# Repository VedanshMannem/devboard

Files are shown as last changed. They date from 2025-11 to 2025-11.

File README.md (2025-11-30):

# Devboard
This project contains all the files of my first devboard. This is great for electronics engineering and hobbyists, with a USBC and RP2040. I included LEDs on this board to make it more flashy, as well as silkscreen art to make it personal. The full BOMs are attached (there's two - one from JLCPCB and one from KiCAD). 

## Setup
All the KiCAD project files are available in the KiCAD folder, and there's photos of the devboard included as well for a rough outline of the end product. Hardest part of this project is honeslty the routing, but as long as you place all the components in the right place, the routing shouldn't be that bad. I went through a few versions of the board to make sure the routing was just right. Try to save the vias for the end as well, its just better practice and I think the board will look less messy without them. 

Here's some photos:






Overall, learned a ton because this was my first full scale PCB project. Thanks for reading!

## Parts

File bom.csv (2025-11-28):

Comment | Designator | Footprint | JLCPCB Part #
10uF | C14,C13 | C_0402_1005Metric | C15525
MCP1700x-330xxTT | U4 | SOT-23 | C39051
33pF | C15,C16 | C_0402_1005Metric | C1562
1K | R5,R7 | R_0402_1005Metric | C11702
LED | D3,D2,D1,D4 | LED_0402_1005Metric_Pad0.77x0.64mm_HandSolder | C71911
Conn_01x03 | J4 | PinHeader_1x03_P2.54mm_Vertical | C92159
5.1K | R2,R1 | R_0402_1005Metric | C25905
12MHz | Y1 | Crystal_SMD_3225-4Pin_3.2x2.5mm | C9002
W25Q16JVSS | U2 | Winbond_USON-8-1EP_3x2mm_P0.5mm_EP0.2x1.6mm | C131025
RP2040 | U1 | QFN-56-1EP_7x7mm_P0.4mm_EP3.2x3.2mm | C2040
1uF | C10,C8 | C_0402_1005Metric | C14445
0.1uF | C7,C12,C11,C6,C2,C9,C1,C4,C3,C17,C5 | C_0402_1005Metric | C1525
Conn_01x20 | J2,J3 | PinHeader_1x20_P2.54mm_Vertical | C247921
10k | R6 | R_0402_1005Metric | C25744
27 | R4,R3 | R_0402_1005Metric | C11616
USB_C_Receptacle_USB2.0_14P | J1 | USB_C_Receptacle_HRO_TYPE-C-31-M-12 | C165948
SW_Push | SW1 | SW_Push_SPST_NO_Alps_SKRK | C720477

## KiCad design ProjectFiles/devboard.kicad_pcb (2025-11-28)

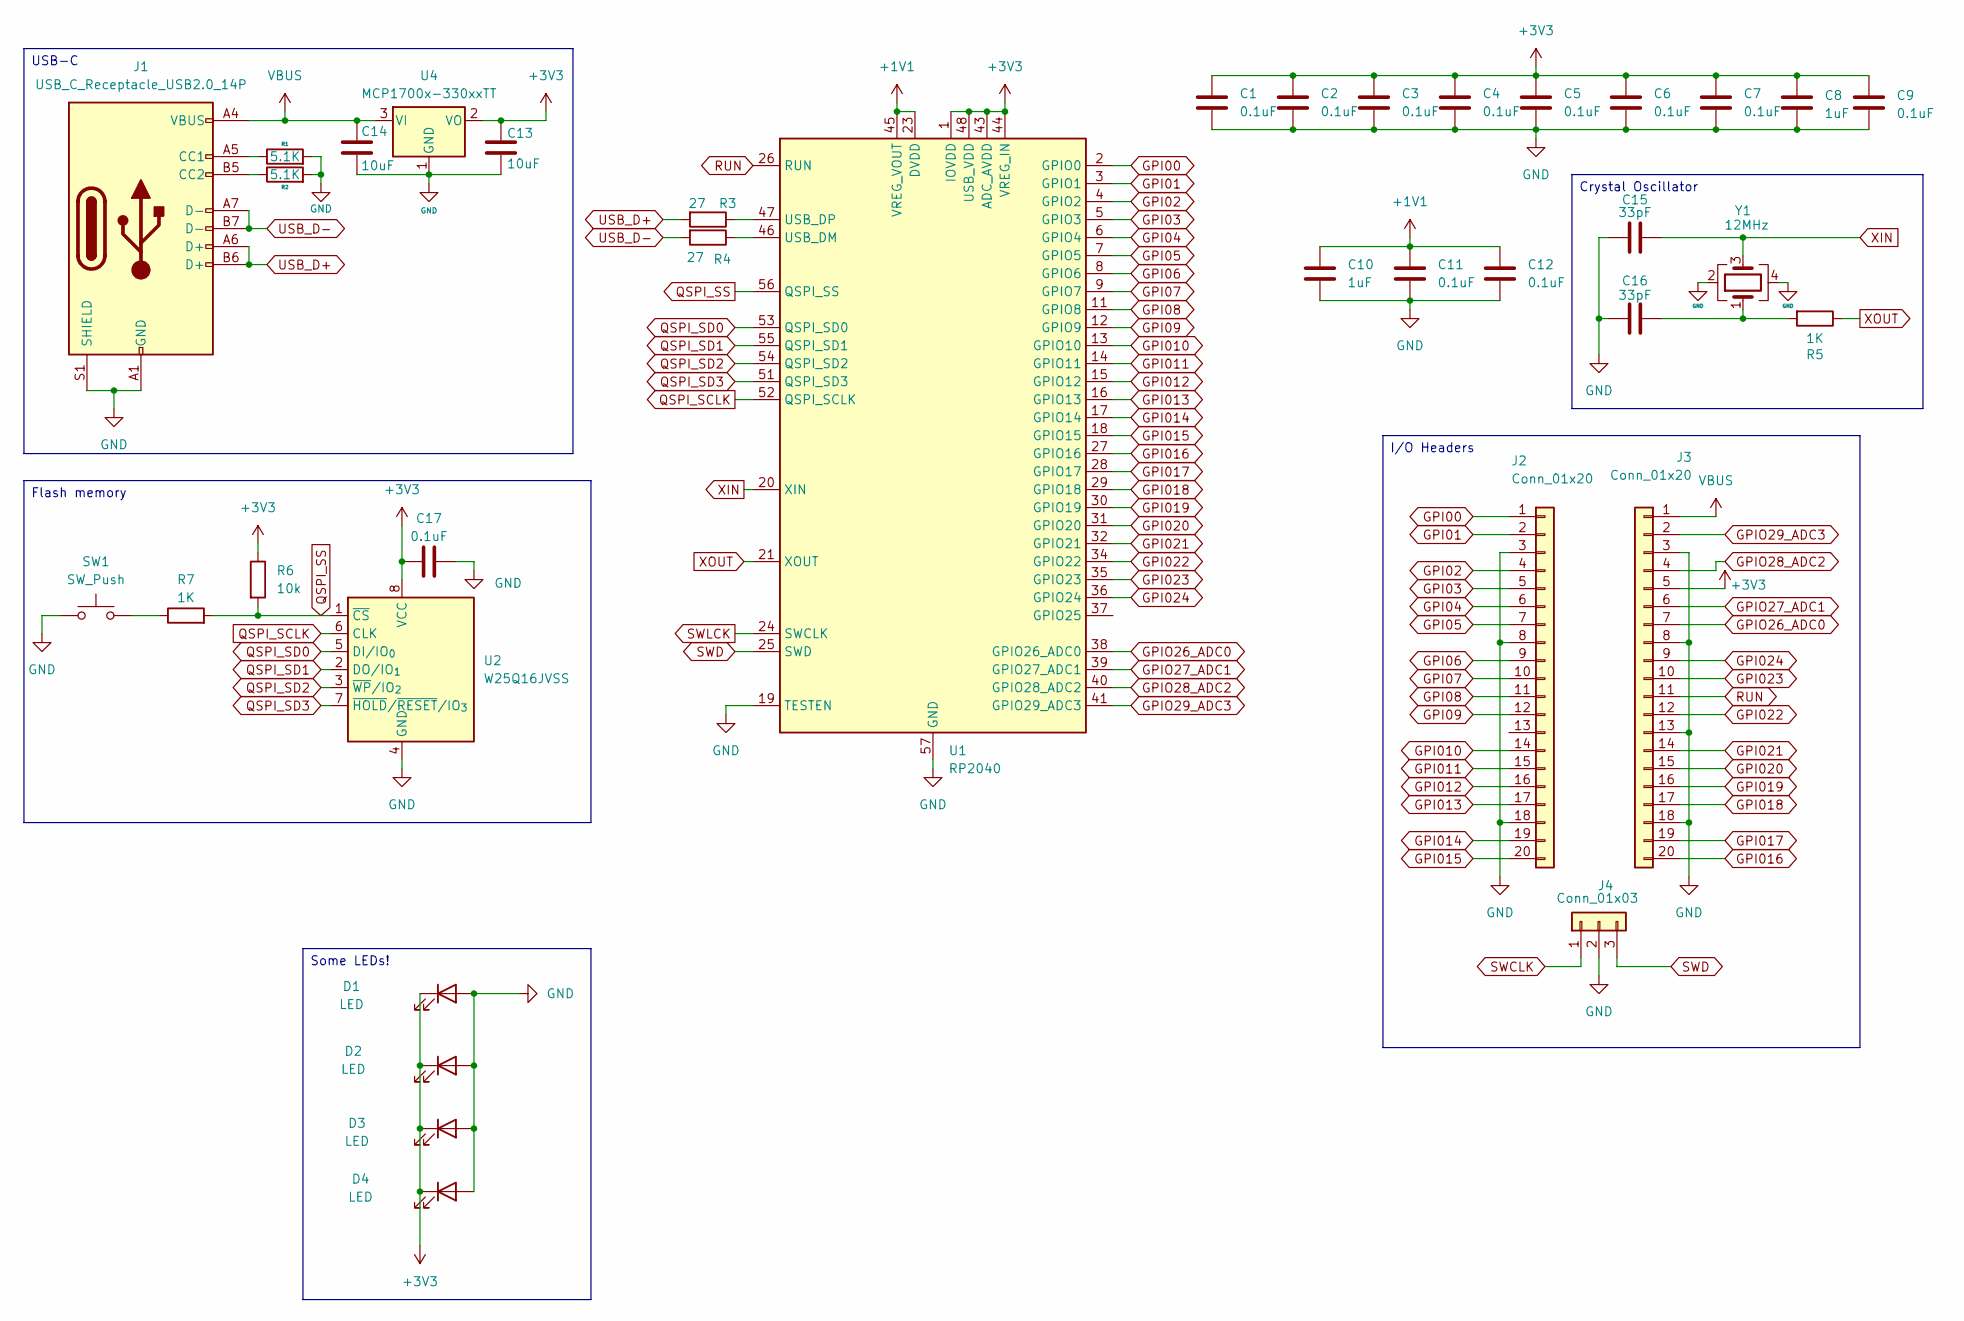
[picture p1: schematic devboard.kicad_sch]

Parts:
C1, C2, C3, C4, C5, C6, C7, C9, C11, C12, C17: 0.1uF; C_0402_1005Metric
C8, C10: 1uF; C_0402_1005Metric
C13, C14: 10uF; C_0402_1005Metric
C15, C16: 33pF; C_0402_1005Metric
D1, D2, D3, D4: LED; LED_0402_1005Metric_Pad0.77x0.64mm_HandSolder
J1: USB_C_Receptacle_USB2.0_14P; USB_C_Receptacle_HRO_TYPE-C-31-M-12
J2, J3: Conn_01x20; PinHeader_1x20_P2.54mm_Vertical
J4: Conn_01x03; PinHeader_1x03_P2.54mm_Vertical
R1, R2: 5.1K; R_0402_1005Metric
R3, R4: 27; R_0402_1005Metric
R5, R7: 1K; R_0402_1005Metric
R6: 10k; R_0402_1005Metric
SW1: SW_Push; SW_Push_SPST_NO_Alps_SKRK
U1: RP2040; QFN-56-1EP_7x7mm_P0.4mm_EP3.2x3.2mm
U2: W25Q16JVSS; Winbond_USON-8-1EP_3x2mm_P0.5mm_EP0.2x1.6mm
U4: MCP1700x-330xxTT; SOT-23
Y1: 12MHz; Crystal_SMD_3225-4Pin_3.2x2.5mm

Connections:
+1V1: C10.1, C11.1, C12.1, U1.23 (DVDD), U1.45 (VREG_VOUT), U1.50 (DVDD)
+3V3: C1.1, C2.1, C3.1, C4.1, C5.1, C6.1, C7.1, C8.1, C9.1, C13.1, C17.1, D1.1 (K), D2.1 (K), D3.1 (K), D4.1 (K), J3.5, R6.1, U1.1 (IOVDD), U1.10 (IOVDD), U1.22 (IOVDD), U1.33 (IOVDD), U1.42 (IOVDD), U1.43 (ADC_AVDD), U1.44 (VREG_IN), U1.48 (USB_VDD), U1.49 (IOVDD), U2.8 (VCC), U4.2 (VO)
GND: C1.2, C2.2, C3.2, C4.2, C5.2, C6.2, C7.2, C8.2, C9.2, C10.2, C11.2, C12.2, C13.2, C14.2, C15.1, C16.1, C17.2, D1.2 (A), D2.2 (A), D3.2 (A), D4.2 (A), J1.A1 (GND), J1.A12 (GND), J1.B1 (GND), J1.B12 (GND), J1.S1 (SHIELD), J2.3, J2.8, J2.18, J3.3, J3.8, J3.13, J3.18, J4.2, R1.2, R2.2, SW1.1, U1.19 (TESTEN), U1.57 (GND), U2.4 (GND), U4.1 (GND), Y1.2, Y1.4
GPI00: J2.1, U1.2 (GPIO0)
GPI01: J2.2, U1.3 (GPIO1)
GPI02: J2.4, U1.4 (GPIO2)
GPI03: J2.5, U1.5 (GPIO3)
GPI04: J2.6, U1.6 (GPIO4)
GPI05: J2.7, U1.7 (GPIO5)
GPI06: J2.9, U1.8 (GPIO6)
GPI07: J2.10, U1.9 (GPIO7)
GPI08: J2.11, U1.11 (GPIO8)
GPI09: J2.12, U1.12 (GPIO9)
GPI010: J2.14, U1.13 (GPIO10)
GPI011: J2.15, U1.14 (GPIO11)
GPI012: J2.16, U1.15 (GPIO12)
GPI013: J2.17, U1.16 (GPIO13)
GPI014: J2.19, U1.17 (GPIO14)
GPI015: J2.20, U1.18 (GPIO15)
GPI016: J3.20, U1.27 (GPIO16)
GPI017: J3.19, U1.28 (GPIO17)
GPI018: J3.17, U1.29 (GPIO18)
GPI019: J3.16, U1.30 (GPIO19)
GPI020: J3.15, U1.31 (GPIO20)
GPI021: J3.14, U1.32 (GPIO21)
GPI022: J3.12, U1.34 (GPIO22)
GPI023: J3.10, U1.35 (GPIO23)
GPI024: J3.9, U1.36 (GPIO24)
GPIO26_ADC0: J3.7, U1.38 (GPIO26_ADC0)
GPIO27_ADC1: J3.6, U1.39 (GPIO27_ADC1)
GPIO28_ADC2: J3.4, U1.40 (GPIO28_ADC2)
GPIO29_ADC3: J3.2, U1.41 (GPIO29_ADC3)
unnamed: C16.2, R5.2, Y1.1
unnamed: J1.A5 (CC1), R1.1
unnamed: J1.B5 (CC2), R2.1
unnamed: R7.1, SW1.2
unnamed: R4.1, U1.46 (USB_DM)
unnamed: R3.1, U1.47 (USB_DP)
QSPI_SCLK: U1.52 (QSPI_SCLK), U2.6 (CLK)
QSPI_SD0: U1.53 (QSPI_SD0), U2.5 (DI/IO_{0})
QSPI_SD1: U1.55 (QSPI_SD1), U2.2 (DO/IO_{1})
QSPI_SD2: U1.54 (QSPI_SD2), U2.3 (~WP/IO_{2})
QSPI_SD3: U1.51 (QSPI_SD3), U2.7 (~HOLD/~RESET/IO_{3})
QSPI_SS: R6.2, R7.2, U1.56 (QSPI_SS), U2.1 (~CS)
RUN: J3.11, U1.26 (RUN)
SWCLK: J4.1
SWD: J4.3, U1.25 (SWD)
SWLCK: U1.24 (SWCLK)
USB_D+: J1.A6 (D+), J1.B6 (D+), R3.2
USB_D-: J1.A7 (D-), J1.B7 (D-), R4.2
VBUS: C14.1, J1.A4 (VBUS), J1.A9 (VBUS), J1.B4 (VBUS), J1.B9 (VBUS), J3.1, U4.3 (VI)
XIN: C15.2, U1.20 (XIN), Y1.3
XOUT: R5.1, U1.21 (XOUT)

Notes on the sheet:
I/O Headers
USB-C
Crystal Oscillator
Flash memory
Some LEDs!

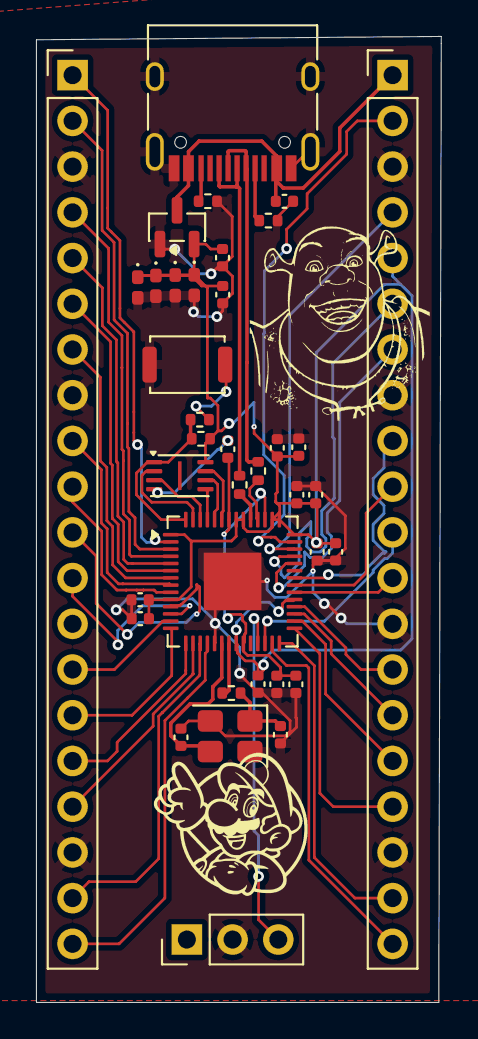
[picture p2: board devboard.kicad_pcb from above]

Board: 2 copper layers, 22.5 x 53.7 mm, 37 parts (0 on the bottom side), 51 nets.

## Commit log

2025-11-28 kiCad files upload
    [BOM.csv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]
2025-11-28 Add project description and images to README
    This project contains all the files of my very own devboard, which is great for engineering and hobbyists, featuring silkscreen art and added LEDs. It includes two BOMs and showcases various photos o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
